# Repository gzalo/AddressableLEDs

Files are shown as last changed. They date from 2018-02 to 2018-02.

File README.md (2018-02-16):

# AddressableLEDs
Driver for WS2812 addressable LEDs. Supports different light effects, and OSC to sync with music beats (planned)

## PCB folder
This folder contains a PCB for a simple addressable LED driver board (based on an ATmega8). It can be opened with the free version of Eagle.

## UC folder
This folder contains the microcontroller code that acts as a bridge between the LED strip and the computer. The microcontroller is connected to a PC using a cheap USB-TTL converter (it must be able to support 256000 bps, so a modern converter is needed, such as cp2102, pl2303, ft232rl).

## PC folder
This folder contains the C++ code that can be used to send patterns to the LEDs. It can be compiled under Linux or Windows, and sends data directly to a serial port. OSC control is planned, not yet implemented.

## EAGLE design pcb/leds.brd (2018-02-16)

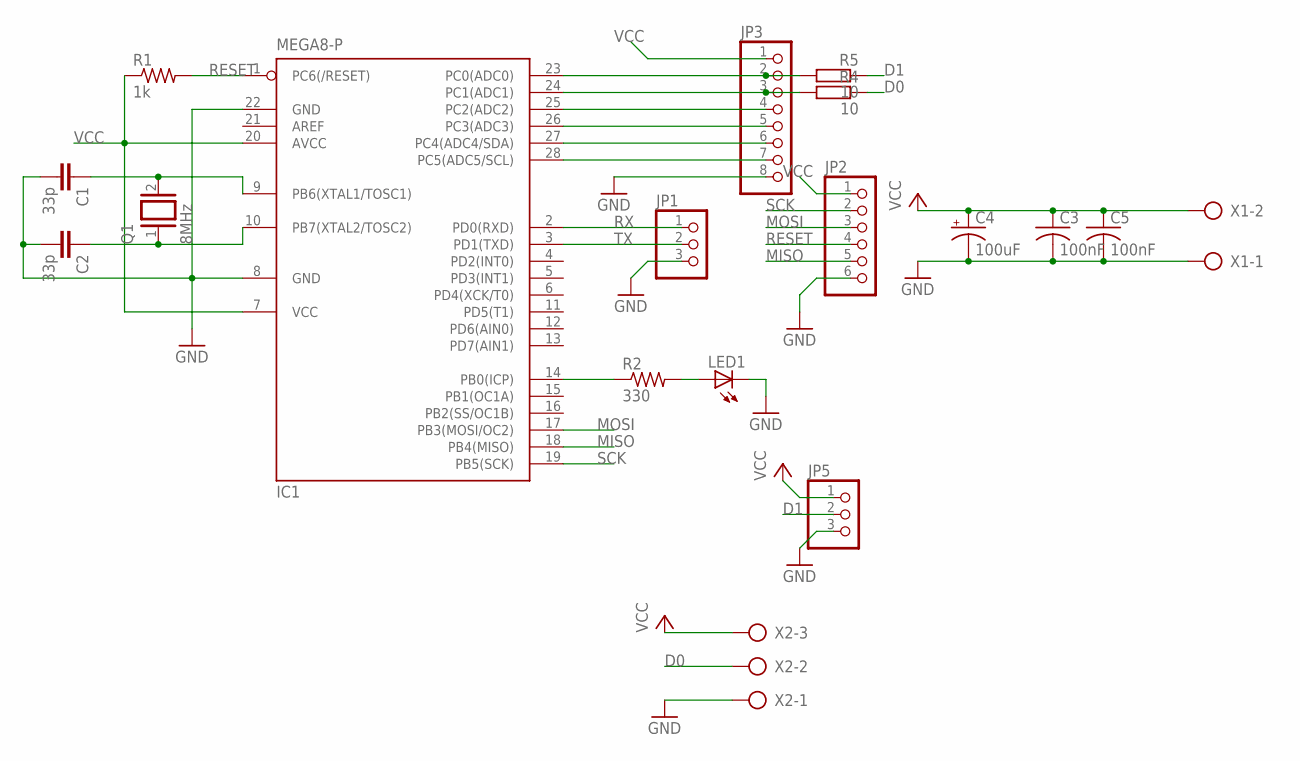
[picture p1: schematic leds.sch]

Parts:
C1, C2: 33p; C025-025X050
C3, C5: 100nF; C0805
C4: 100uF; E5-8,5
IC1: MEGA8-P; DIL28-3
JP1, JP5: PINHD-1X3; 1X03
JP2: PINHD-1X6; 1X06
JP3: PINHD-1X8; 1X08
LED1: LED3MM
Q1: 8MHz; QS
R1: 1k; M0805
R2: 330; M0805
R4, R5: 10; 0204/7
X1: AK500/2
X2: AK500/3

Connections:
D0: R4.1, X2.2
D1: JP5.2, R5.1
GND: C1.2, C2.2, C3.2, C4.-, C5.2, IC1.8 (GND), IC1.22 (GND), JP1.3, JP2.6, JP3.8, JP5.3, LED1.K (C), X1.1, X2.1
MISO: IC1.18 (PB4(MISO)), JP2.5
MOSI: IC1.17 (PB3(MOSI/OC2)), JP2.3
unnamed: IC1.27 (PC4(ADC4/SDA)), JP3.6
unnamed: IC1.23 (PC0(ADC0)), JP3.2, R5.2
unnamed: C1.1, IC1.9 (PB6(XTAL1/TOSC1)), Q1.2
unnamed: C2.1, IC1.10 (PB7(XTAL2/TOSC2)), Q1.1
unnamed: IC1.24 (PC1(ADC1)), JP3.3, R4.2
unnamed: IC1.25 (PC2(ADC2)), JP3.4
unnamed: IC1.26 (PC3(ADC3)), JP3.5
unnamed: IC1.28 (PC5(ADC5/SCL)), JP3.7
unnamed: IC1.14 (PB0(ICP)), R2.1
unnamed: LED1.A, R2.2
RESET: IC1.1 (PC6(/RESET)), JP2.4, R1.2
RX: IC1.2 (PD0(RXD)), JP1.1
SCK: IC1.19 (PB5(SCK)), JP2.2
TX: IC1.3 (PD1(TXD)), JP1.2
VCC: C3.1, C4.+, C5.1, IC1.7 (VCC), IC1.20 (AVCC), JP2.1, JP3.1, JP5.1, R1.1, X1.2, X2.3

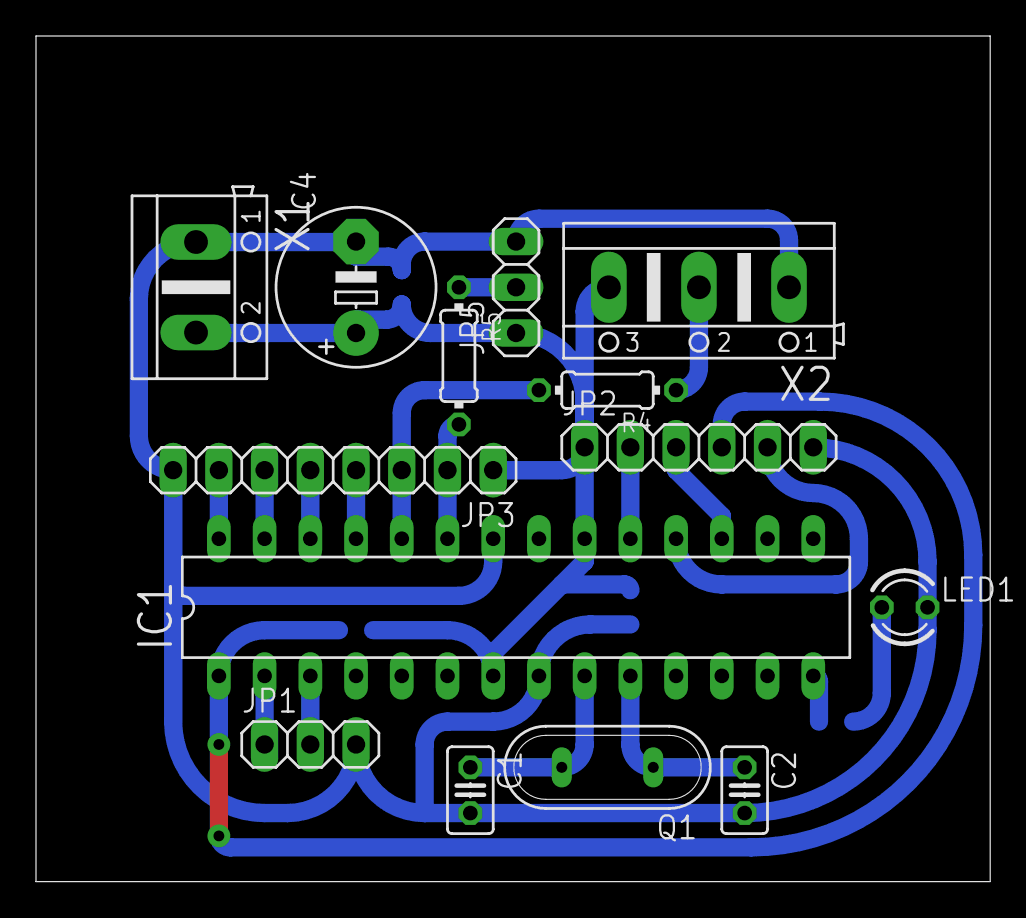
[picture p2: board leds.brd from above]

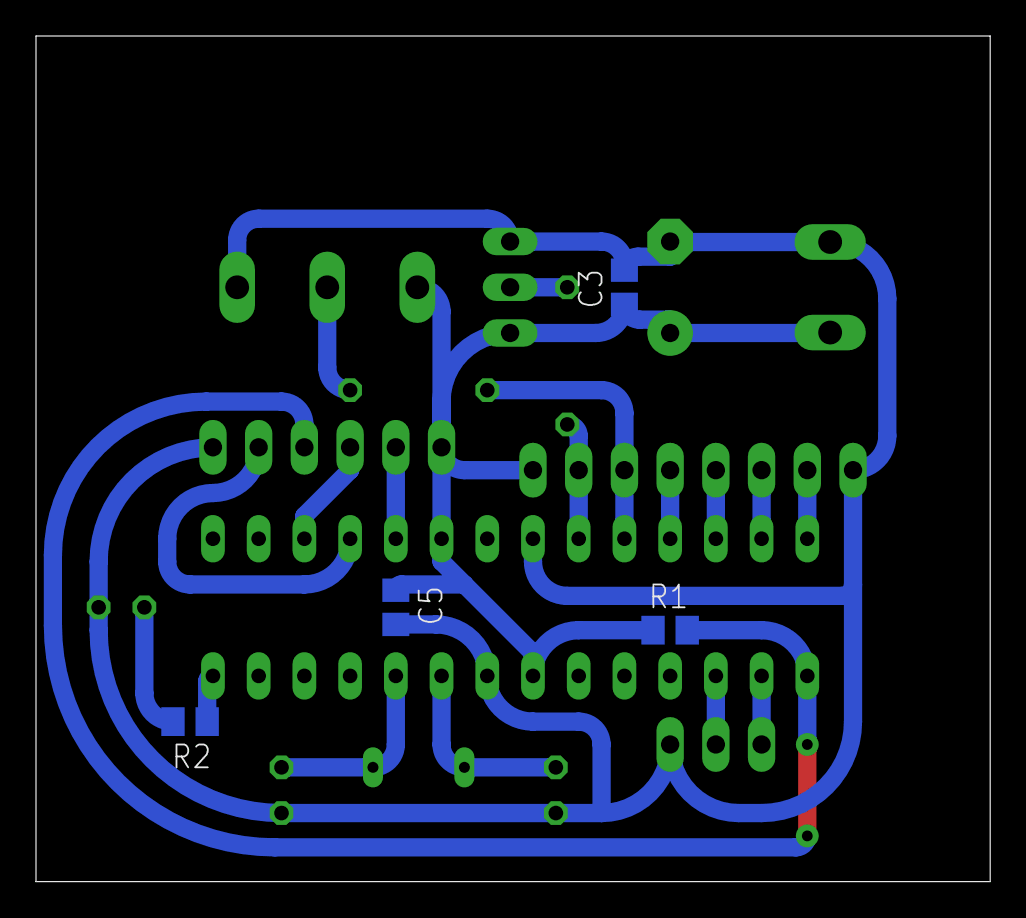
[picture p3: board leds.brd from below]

Board: 2 copper layers, 53.0 x 47.0 mm, 18 parts (4 on the bottom side), 20 nets.

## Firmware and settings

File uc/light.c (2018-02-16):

/*

	Addressable LEDs, microcontroller code
	
	Receives data via the serial port (at 256 kbps), buffers it and then sends the values to the strip. 
	Edit ws2812_config.h if you want to change the data pin of the strip.
	
	Data format:
	
	0xFF 		   Delimiter
	0xRR 0xGG 0xBB First LED color
	0xRR 0xGG 0xBB Second LED color 
	0xRR 0xGG 0xBB Third LED color 
	....
	0xRR 0xGG 0xBB LED_COUNTth LED color
	
	0xFF  		   Delimiter
	0xRR 0xGG 0xBB First LED color
	... (the cycle restarts)
	
	
	To avoid syncing to the wrong part of the data, the 0xFF character 
	should only be used for the delimiter. This limits the maximum intensity of the LEDs to 0xFEFEFE, but its not really noticeable.
*/

#define F_CPU 16000000

/*
	Approx TIMING:
		4.4 ms update LEDs
		14.10 ms reception (at 256 kbps)
*/

#include <avr/io.h>
#include <util/delay.h>
#include <avr/interrupt.h>
#include <string.h>

#include "light_ws2812.h"

//Update this line to the length of the LED strip used
#define LED_COUNT 120 
struct cRGB colors[LED_COUNT];

//I/O pin initialization
void boardInit(){
	DDRB = 0b00000001;
	DDRD = 0b00000000;
	DDRC = 0b00000000;	
}

void toggleOnBoardLed(){
	PORTB ^= 1; 
}
void setOnBoardLed(uint8_t val){
	if(val == 1){
		PORTB |= 0x01; 
	}else{
		PORTB &= 0xFE; 
	}
}

#define BAUD 256000
#define BAUDRATE ((F_CPU+BAUD*8UL)/(BAUD*16UL)-1UL)

void uartInit(){
	UBRRH = (uint8_t)(BAUDRATE>>8);
	UBRRL = (uint8_t)(BAUDRATE);

	UCSRB = (1<<RXEN)|(1<<TXEN);
	UCSRC = (1<<URSEL)|(3<<UCSZ0);	
}
uint8_t getchar(){
	while(!(UCSRA & (1<<RXC)));
	return UDR;
}

int main(){
	uint8_t i;
	
	boardInit();
	uartInit();
	
	_delay_ms(100);
	setOnBoardLed(1);
	_delay_ms(500);
	setOnBoardLed(0);
			
	while(1){

		while(getchar()!=0xFF); //Wait for delimiter
		toggleOnBoardLed();
		
		for(i=0;i<LED_COUNT;i++){
			colors[i].r = getchar();
			colors[i].g = getchar();
			colors[i].b = getchar();
		}
		
		ws2812_setleds(colors, LED_COUNT);
	}
}
